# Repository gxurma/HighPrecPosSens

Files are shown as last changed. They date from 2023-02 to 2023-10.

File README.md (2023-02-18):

# HighPrecPosSens

High precision Position Sensor System using
* Hamamatsu s12443, 
* a gradient lens array,
* a paper or metal stripe / code encoder scale 
* an RP2040 or Teensy 4.1 µC board.

## s12443

Pixel size: 7 x 125 μm, 2496 pixels, small package

The S12443 is a CMOS linear image sensor with a compact yet 2496-pixel long photosensitive area (effective photosensitive area length: 17.472 mm). The pixel size is 7 x 125 μm.

* Features
* Pixel size: 7 × 125 μm
* 2496 pixels
* Effective photosensitive area length: 17.472 mm
* 3.3 V single power supply operation
* Built-in timing generator allows operation with only Start and Clock pulse inputs
* Video data rate: 10 MHz max.
* Small imput terminal capacitance: 5 pF

In my experiments I saw that 10MHz usage is leading to higher noise levels.

I recommend 5 MHz pxel clock signal, thats nicely representing the measured analog signal.

## Credits to

https://github.com/ncarandini/KiCad-RP-Pico.git

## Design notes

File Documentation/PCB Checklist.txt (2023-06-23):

Pcb und Assembly: Checkliste
============================
Martin Gyurkó <martin.gyurko@engyneer.de>
v1.0, {docdate}: valami
:toc:
:toclevels: 3
:icons: font
:doctype: article
:chapter-label:
:table-stripes: odd

* [ ] Kontur
* [ ] Bohrungen
* [ ] Copyright 
* [ ] Author Name
* [ ] Device Name
* [ ] Versionsnummer
* [ ] JlcPcb String
* [ ] Mounting attribute at relevant parts, Do not populate (DNP) if not needed
* [ ] Net names on relevant and all power nets
* [ ] Set net classes to power and signal
* [ ] Logo!
* [ ] Testpunkte!
* [ ] Via bohrdurchmesser checken und alle einheitlich anpassen
* [ ] Stecker Footprints checken - Male / Female
* [ ] Layer Stackup Beschreibung einfügen (Lagendicken, material etc.)
* [ ] DRC Regeln einstellen und durchführen

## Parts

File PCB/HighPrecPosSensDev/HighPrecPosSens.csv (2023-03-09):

Comment | Designator | Footprint | LCSC Part # | Mounting
100n Unpolarized capacitor | C1,C3,C9,C10,C13,C14,C16,C21 | C_0603_1608Metric | C14663
10u Unpolarized capacitor | C2 | C_0805_2012Metric_Pad1.18x1.45mm_HandSolder | C440198
100u Unpolarized capacitor | C4 | C_1206_3216Metric_Pad1.33x1.80mm_HandSolder | C15008
150p Unpolarized capacitor | C5 | C_0603_1608Metric | C1594
22u Unpolarized capacitor | C6,C7,C11,C12,C15 | C_0603_1608Metric | C59461
1u Unpolarized capacitor | C8,C17,C18,C19,C20 | C_0603_1608Metric | C15849
LED Light emitting diode | D1,D2,D3,D4,D5,D6,D7,D9,D10,D11,D12,D13,D14,D15 | LED_0603_1608Metric_Pad1.05x0.95mm_HandSolder | C72041
SS36 Schottky diode, filled shape | D8 | D_SMC_Handsoldering | C35722
Fiducial Fiducial Marker | FID1,FID2,FID3,FID4 | Fiducial_1mm_Mask2mm |  | DNP
LOGO | G1 | enGyneer-Logo |  | DNP
MountingHole_Pad Mounting Hole with connection | H1,H2,H3,H4 | MountingHole_3.2mm_M3_Pad |  | DNP
Conn_01x02_Male Generic connector, single row, 01x02, script generated (kicad-library-utils/schlib/autogen/connector/) | J1,J2,J3,J4,J6,J7,J8 | PinHeader_1x02_P2.54mm_Vertical |  | DNP
Conn_01x06_Male Generic connector, single row, 01x06, script generated (kicad-library-utils/schlib/autogen/connector/) | J5 | JST_XH_B6B-XH-A_1x06_P2.50mm_Vertical | C144397 | DNP
10u Inductor | L1 | L_Taiyo-Yuden_NR-50xx_HandSoldering | C222896
82 Resistor | R1,R5,R6,R7,R8,R15,R16,R17,R18,R19,R20,R25,R26,R27,R28,R29 | R_0603_1608Metric | C23255
47k Resistor | R2 | R_0603_1608Metric | C25819
4.7k Resistor | R3 | R_0603_1608Metric | C23162
2.7k Resistor | R4 | R_0603_1608Metric | C13167
100 Resistor | R9 | R_0603_1608Metric | C22775
3.6k Resistor | R10 | R_0603_1608Metric | C22980
1k Resistor | R11,R12,R13,R21,R22,R23,R24 | R_0603_1608Metric | C21190
4.3k Resistor | R14 | R_0603_1608Metric | C23159
TestPoint test point | TP1,TP2,TP3,TP4 | TestPoint_THTPad_D1.5mm_Drill0.7mm |  | DNP
ST1S14PHR 3A step-down switching regulator, Adjustable Output Voltage, 5.5-48V Input Voltage, 850kHz, PowerSO-8 | U1 | TI_SO-PowerPAD-8 | C84130
S12443 Hamamatsu Linear CMOS Sensor 7 x 125µm, 2496 pixels | U2 | s12443 |  | DNP
LM393DR2G Low-Power, Low-Offset Voltage, Dual Comparators, DIP-8/SOIC-8/TO-99-8 | U3,U4 | SOIC-8_3.9x4.9mm_P1.27mm | C7955
74LVC541A 8-bit Buffer/Line Driver 3-state outputs | U5 | TSSOP-20_4.4x6.5mm_P0.65mm | C6093
Pico | U6 | RPi_Pico_SMD_TH |  | DNP

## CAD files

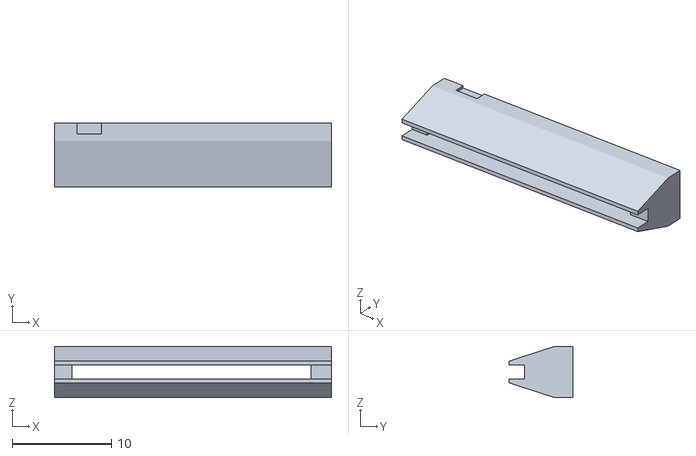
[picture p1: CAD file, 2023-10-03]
PCB/HighPrecPosSensDev/Deckel2.stl
27.9 x 6.40 x 5.19

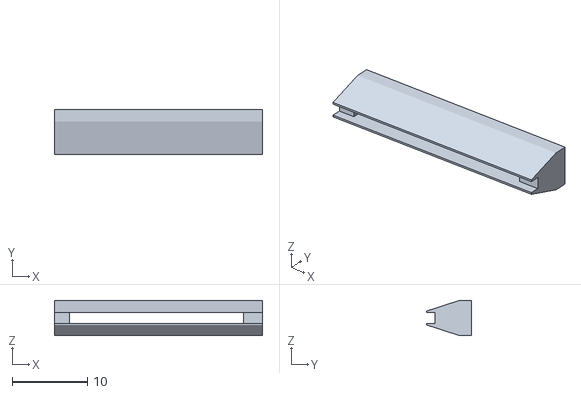
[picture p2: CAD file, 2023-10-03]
PCB/HighPrecPosSensDev/Deckel.stl
27.7 x 6.00 x 4.69

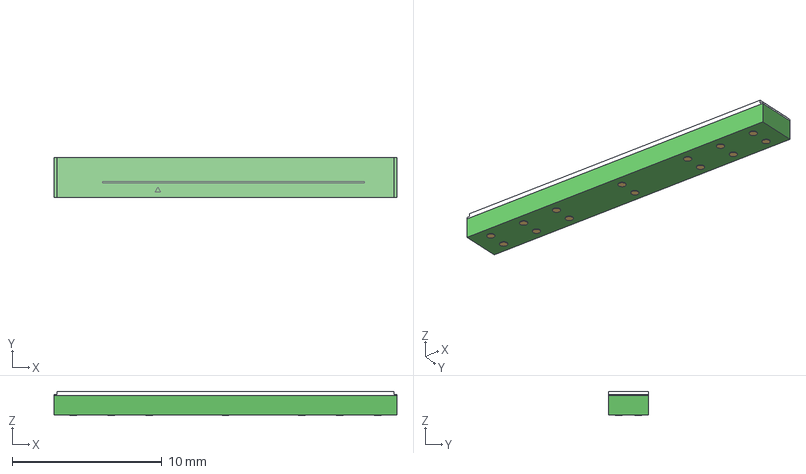
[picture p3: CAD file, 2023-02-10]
CAD/s12443.stp
22.9 x 2.70 x 1.64 mm
s12443
s12443_deckel
s12443_pads

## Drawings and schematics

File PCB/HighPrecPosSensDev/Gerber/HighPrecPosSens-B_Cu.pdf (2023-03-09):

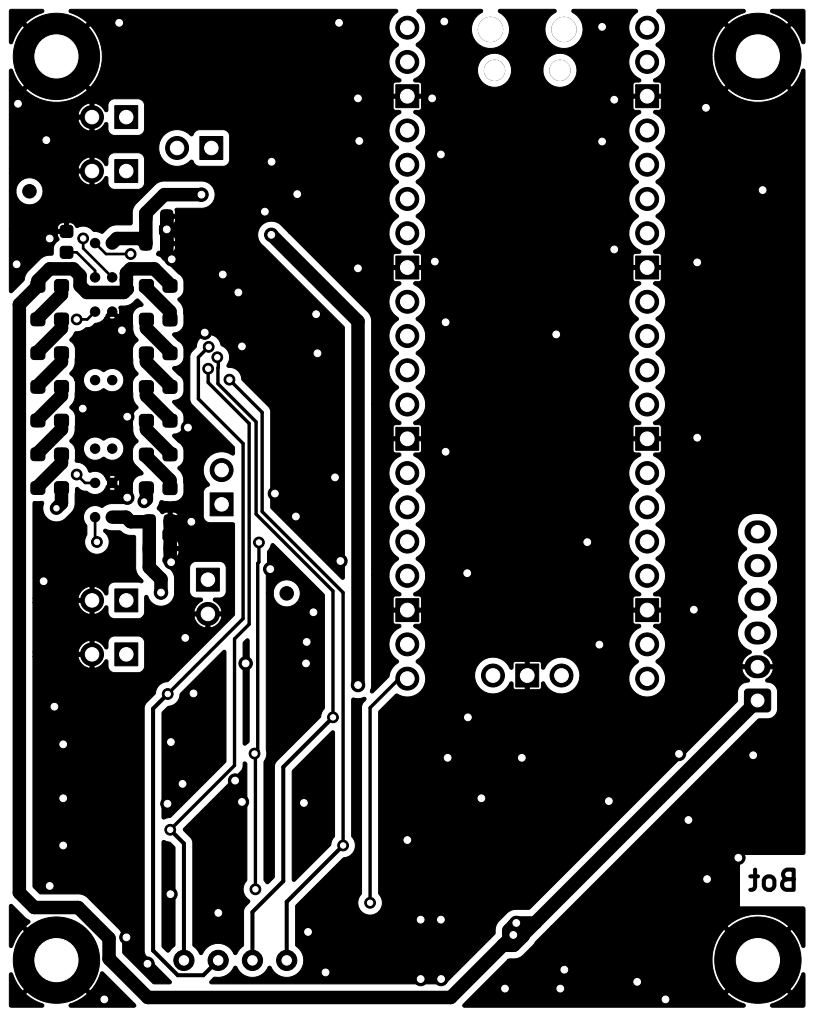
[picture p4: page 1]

www.enGyneer.de Bot

File: HighPrecPosSens.kicad_pcb Sheet: enGyneer

Id: 1/1 Title: High Precision Position Sensor

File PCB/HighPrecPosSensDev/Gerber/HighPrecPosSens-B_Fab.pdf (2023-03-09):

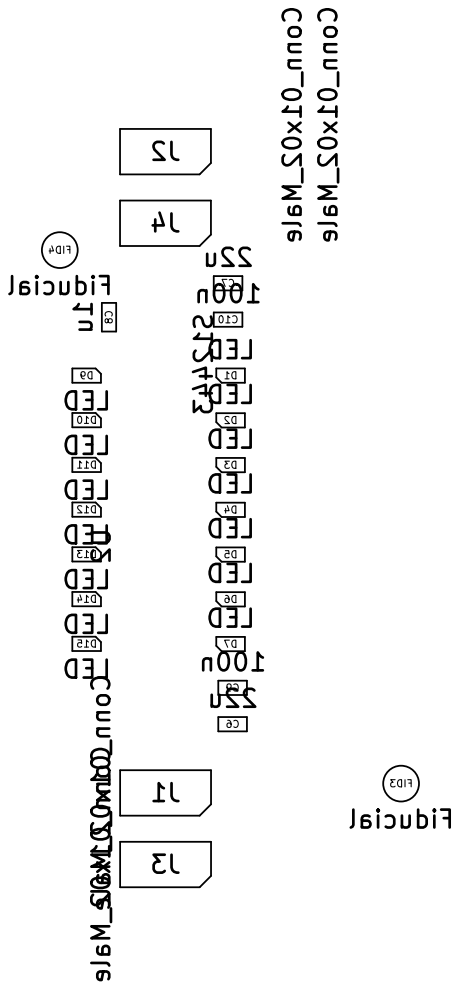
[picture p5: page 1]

File: HighPrecPosSens.kicad_pcb Sheet: enGyneer

Id: 1/1 Title: High Precision Position Sensor

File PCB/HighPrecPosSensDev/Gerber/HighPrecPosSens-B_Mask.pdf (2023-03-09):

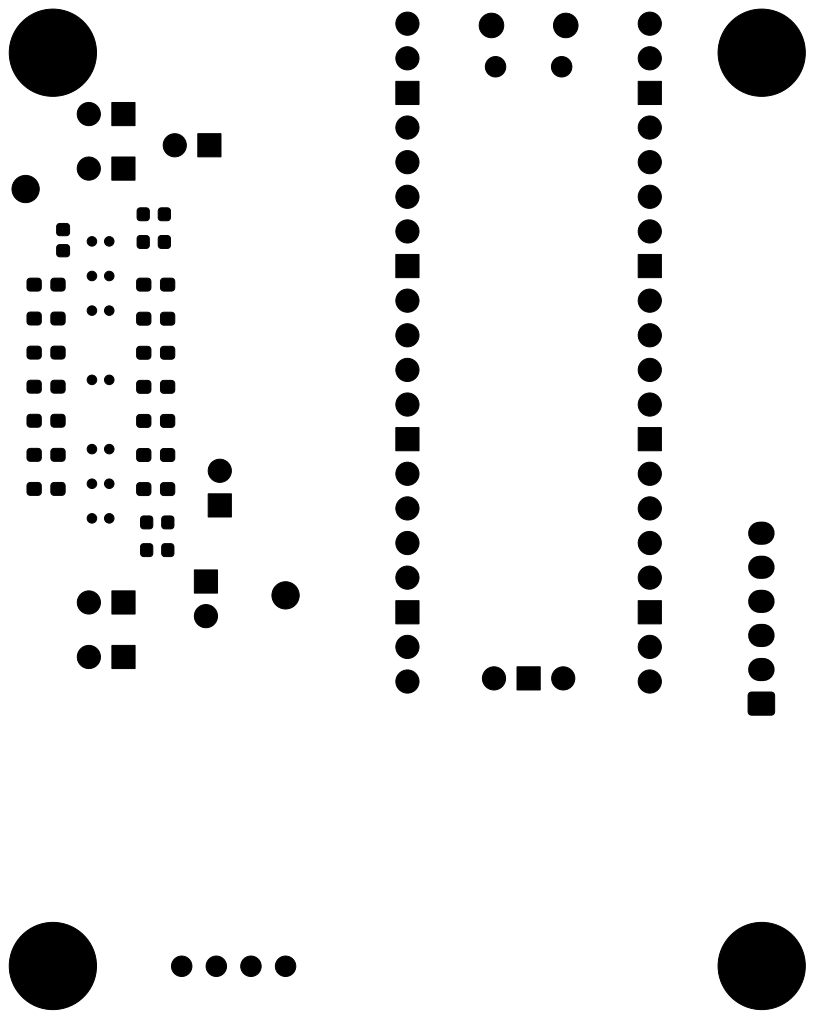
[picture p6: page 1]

File: HighPrecPosSens.kicad_pcb Sheet: enGyneer

Id: 1/1 Title: High Precision Position Sensor

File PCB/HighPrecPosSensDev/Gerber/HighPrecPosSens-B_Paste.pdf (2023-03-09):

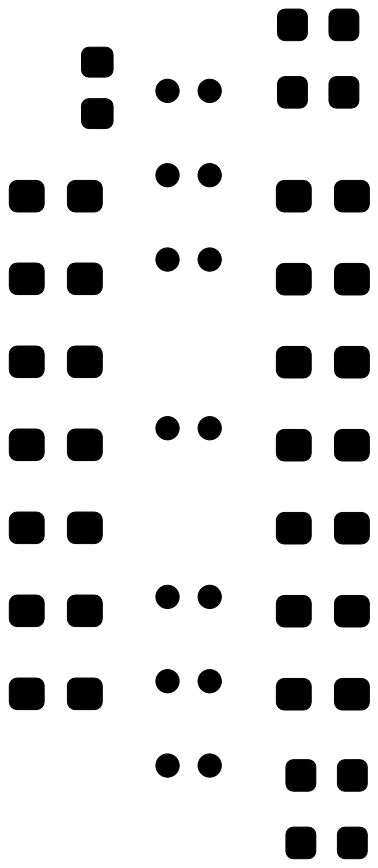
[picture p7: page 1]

File: HighPrecPosSens.kicad_pcb Sheet: enGyneer

Id: 1/1 Title: High Precision Position Sensor

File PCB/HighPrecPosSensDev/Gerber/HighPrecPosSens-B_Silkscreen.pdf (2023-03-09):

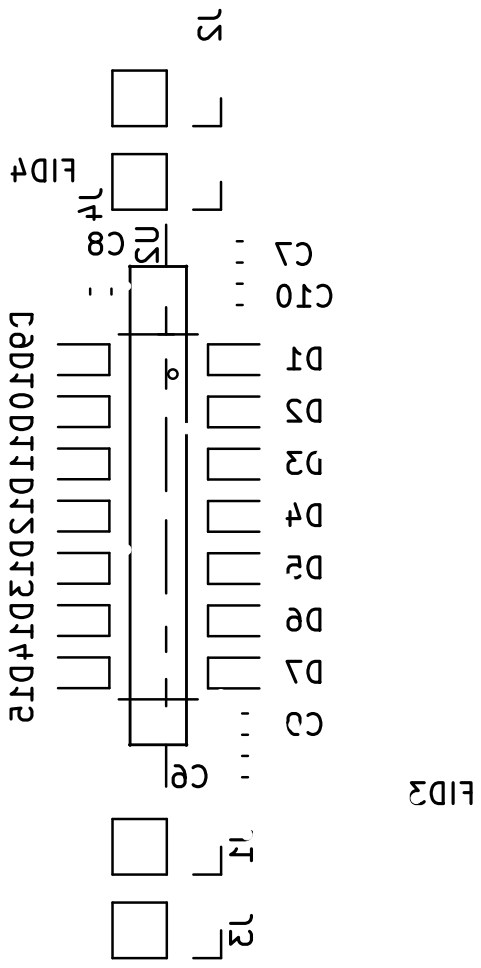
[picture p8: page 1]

File: HighPrecPosSens.kicad_pcb Sheet: enGyneer

Id: 1/1 Title: High Precision Position Sensor

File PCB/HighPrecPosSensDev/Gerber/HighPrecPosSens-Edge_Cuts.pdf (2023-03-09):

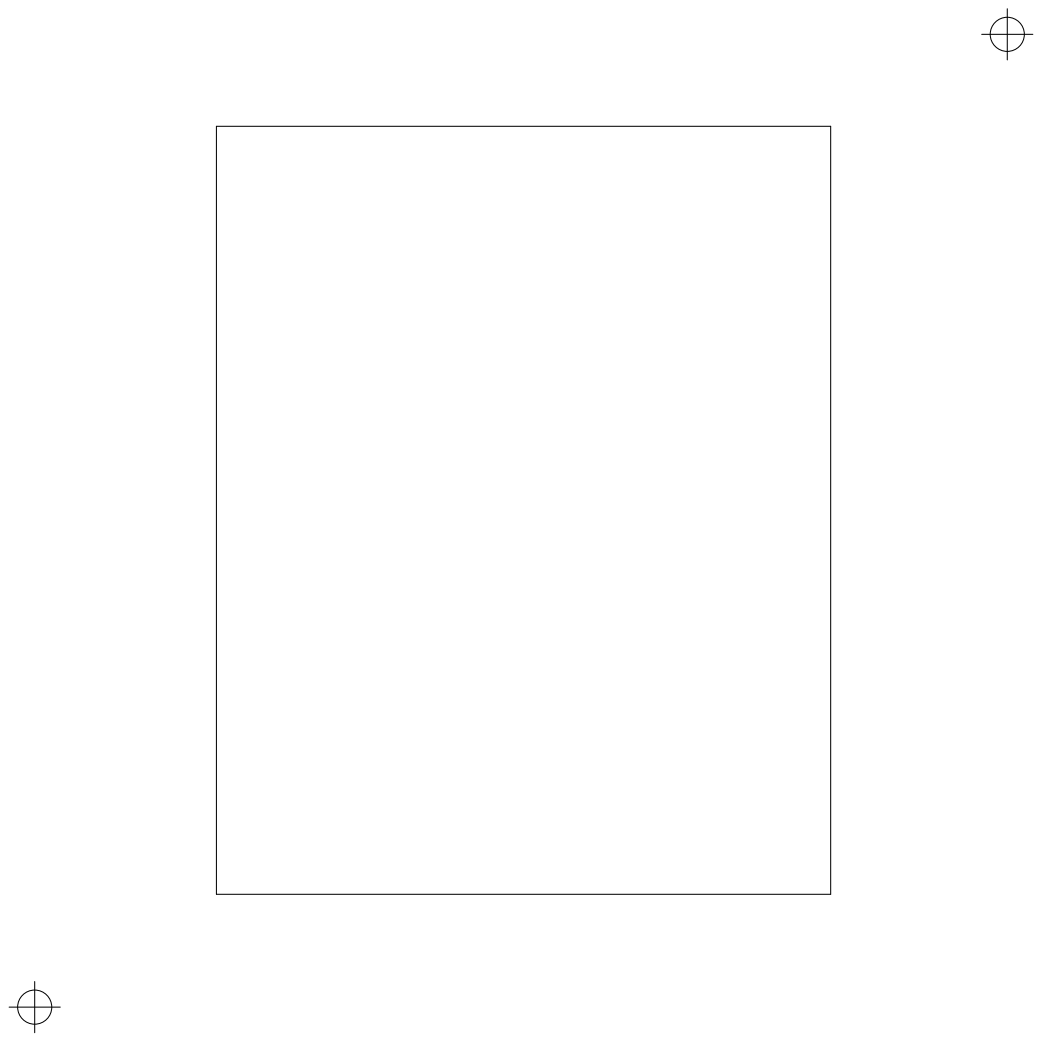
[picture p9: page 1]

File: HighPrecPosSens.kicad_pcb Sheet: enGyneer

Id: 1/1 Title: High Precision Position Sensor

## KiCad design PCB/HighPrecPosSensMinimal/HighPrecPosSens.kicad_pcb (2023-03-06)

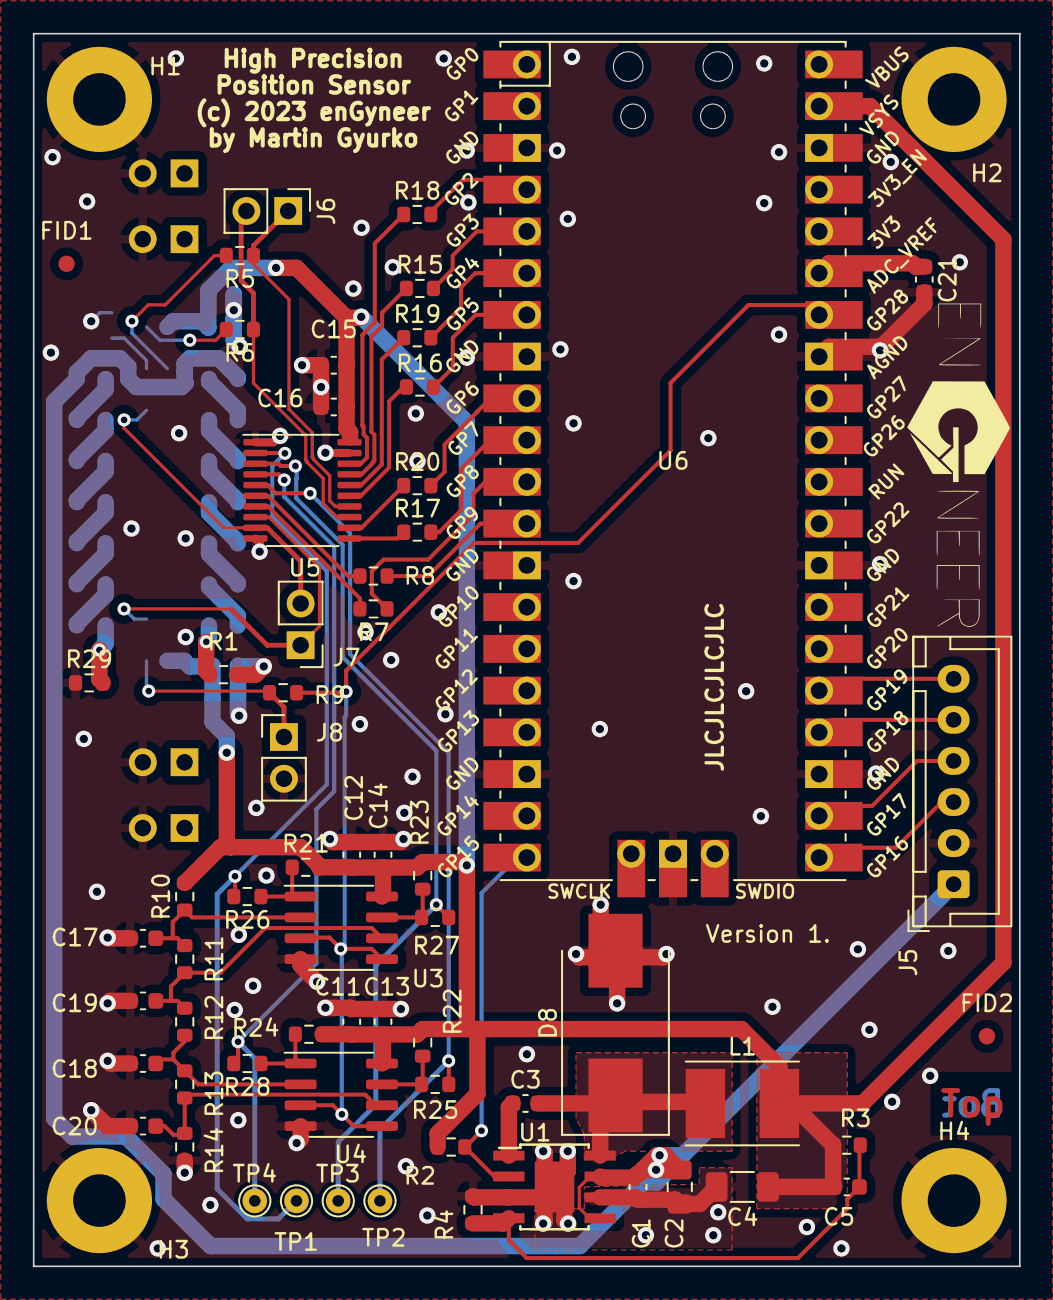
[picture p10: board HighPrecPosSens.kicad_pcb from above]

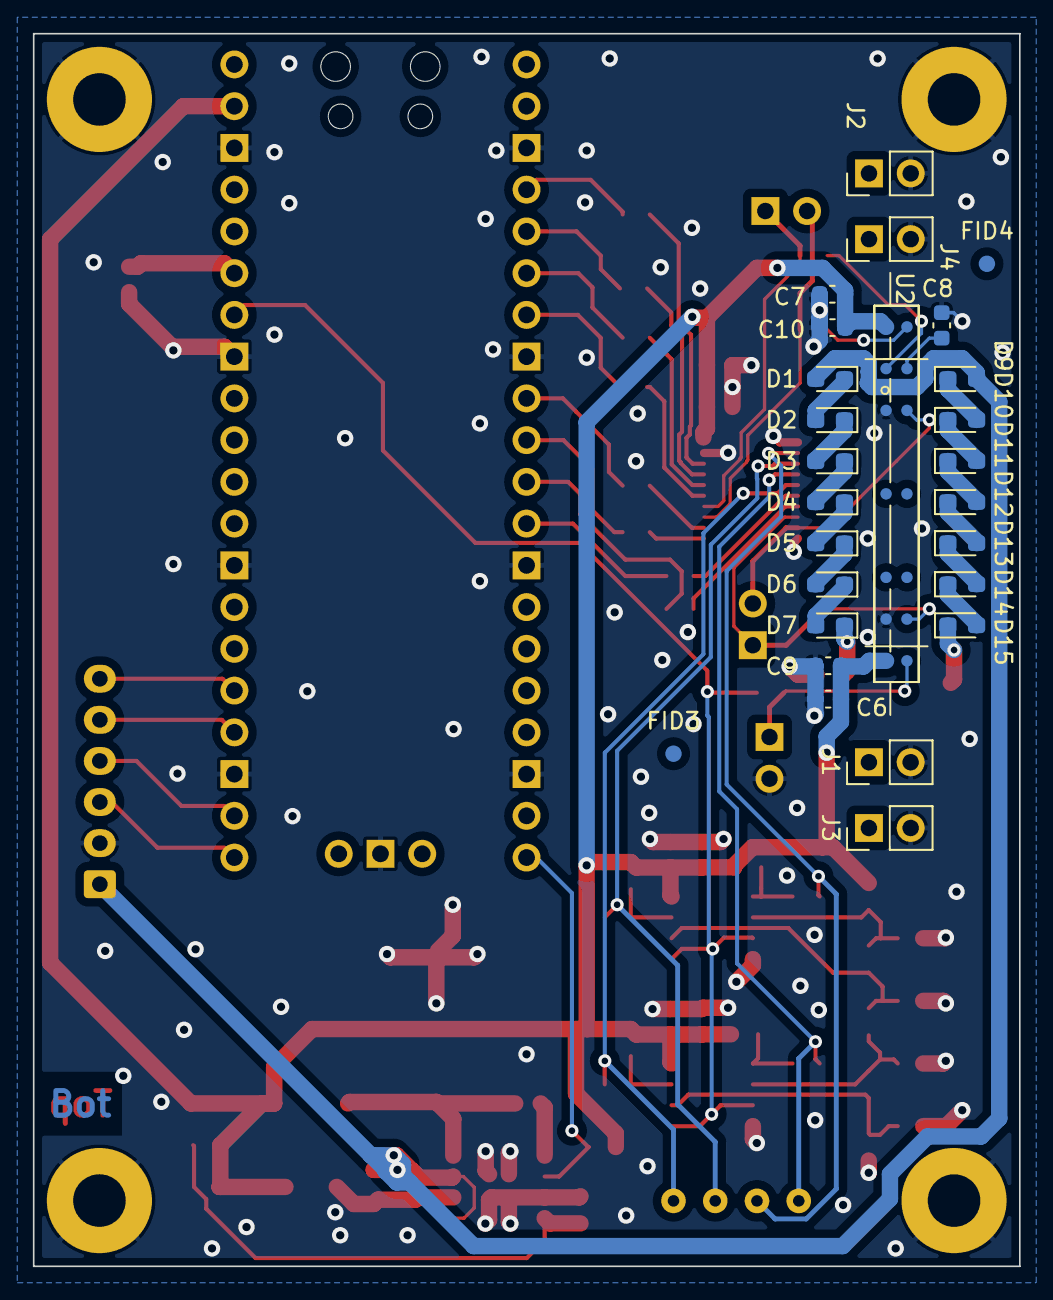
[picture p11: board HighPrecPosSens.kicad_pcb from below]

Board: 2 copper layers, 60.0 x 75.0 mm, 93 parts (26 on the bottom side), 63 nets.

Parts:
C1, C3, C9, C10, C13, C14, C16, C21: 100n; C_0603_1608Metric
C2: 10u; C_0805_2012Metric_Pad1.18x1.45mm_HandSolder
C4: 100u; C_1206_3216Metric_Pad1.33x1.80mm_HandSolder
C5: 150p; C_0603_1608Metric
C6, C7, C11, C12, C15: 22u; C_0603_1608Metric
C8, C17, C18, C19, C20: 1u; C_0603_1608Metric
D1, D2, D3, D4, D5, D6, D7, D9, D10, D11, D12, D13, D14, D15: LED; LED_0603_1608Metric_Pad1.05x0.95mm_HandSolder
D8: SS36; D_SMC_Handsoldering
FID1, FID2, FID3, FID4: Fiducial; Fiducial_1mm_Mask2mm
G1: LOGO; enGyneer-Logo
H1, H2, H3, H4: MountingHole_Pad; MountingHole_3.2mm_M3_Pad
J1, J2, J3, J4, J6, J7, J8: Conn_01x02_Male; PinHeader_1x02_P2.54mm_Vertical
J5: Conn_01x06_Male; JST_XH_B6B-XH-A_1x06_P2.50mm_Vertical
L1: 10u; L_Taiyo-Yuden_NR-50xx_HandSoldering
R1, R5, R6, R7, R8, R15, R16, R17, R18, R19, R20, R25, R26, R27, R28, R29: 82; R_0603_1608Metric
R2: 47k; R_0603_1608Metric
R3: 4.7k; R_0603_1608Metric
R4: 2.7k; R_0603_1608Metric
R9: 100; R_0603_1608Metric
R10: 3.6k; R_0603_1608Metric
R11, R12, R13, R21, R22, R23, R24: 1k; R_0603_1608Metric
R14: 4.3k; R_0603_1608Metric
TP1, TP2, TP3, TP4: TestPoint; TestPoint_THTPad_D1.5mm_Drill0.7mm
U1: ST1S14PHR; TI_SO-PowerPAD-8
U2: S12443; s12443
U3, U4: LM393DR2G; SOIC-8_3.9x4.9mm_P1.27mm
U5: 74LVC541A; TSSOP-20_4.4x6.5mm_P0.65mm
U6: Pico; RPi_Pico_SMD_TH

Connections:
+3.3V: C4.1, C5.1, C6.1, C7.1, C9.1, C10.1, C11.1, C12.1, C13.1, C14.1, C15.1, C16.1, L1.2, R2.1, R3.2, R10.2, R21.2, R22.2, R23.2, R24.2, U2.1 (Vdd), U2.7 (Vdd), U3.8 (V+), U4.8 (V+), U5.20 (VCC), U6.39 (VSYS)
+24V: C1.1, C2.1, D1.2 (A), D9.2 (A), J5.1, U1.5 (EN2), U1.7 (VIN)
/Boot: C3.1, U1.1 (BOOT)
/CLk: J6.1, R5.1, U5.14 (Y4)
/Clk_2: R5.2, U2.2 (Clk)
/D1: R25.2, TP2.1, U5.5 (A3)
/D2: R28.2, TP4.1, U5.4 (A2)
/D3: R27.2, TP3.1, U5.3 (A1)
/D4: R26.2, TP1.1, U5.2 (A0)
/EOS: J7.1, U2.9 (EOS), U5.8 (A6)
/FB: C5.2, R3.1, R4.2, U1.4 (FB)
/ST: J6.2, R6.1, U5.13 (Y5)
/ST_2: R6.2, U2.14 (ST)
/Switch: C3.2, D8.1 (K), L1.1, U1.8 (SW)
/Trig: J7.2, U2.12 (Trig), U5.9 (A7)
/V1: C20.1, R13.1, R14.2, U4.6 (-)
/V2: C18.1, R12.1, R13.2, U4.2 (-)
/V3: C19.1, R11.1, R12.2, U3.6 (-)
/V4: C17.1, R10.1, R11.2, U3.2 (-)
/Video: J8.1, R9.1, U2.8 (Video)
/Video1: R9.2, U3.3 (+), U3.5 (+), U4.3 (+), U4.5 (+), U6.34 (GPIO28_ADC2)
GND: C1.2, C2.2, C4.2, C6.2, C7.2, C8.2, C9.2, C10.2, C11.2, C12.2, C13.2, C14.2, C15.2, C16.2, C17.2, C18.2, C19.2, C20.2, C21.2, D8.2 (A), H1.1, H2.1, H3.1, H4.1, J1.2, J2.2, J3.2, J4.2, J5.2, J8.2, R1.1, R4.1, R14.1, R29.1, U1.3 (~EN1), U1.6 (GND), U1.9 (PADGND), U2.3 (Vss), U2.6 (Vss), U3.4 (V-), U4.4 (V-), U5.1 (G1), U5.10 (GND), U5.19 (G2), U6.3 (GND), U6.8 (GND), U6.13 (GND), U6.18 (GND), U6.23 (GND), U6.28 (GND), U6.33 (AGND), U6.38 (GND), U6.42 (GND)
Miso: J5.3, U6.21 (GPIO16)
Mosi: J5.6, U6.25 (GPIO19)
unnamed: C8.1, U2.13 (Vcp)
unnamed: C21.1, U6.35 (ADC_VREF)
unnamed: D1.1 (K), D2.2 (A)
unnamed: D2.1 (K), D3.2 (A)
unnamed: D3.1 (K), D4.2 (A)
unnamed: D4.1 (K), D5.2 (A)
unnamed: D5.1 (K), D6.2 (A)
unnamed: D6.1 (K), D7.2 (A)
unnamed: D7.1 (K), R1.2
unnamed: D10.1 (K), D11.2 (A)
unnamed: D9.1 (K), D10.2 (A)
unnamed: D11.1 (K), D12.2 (A)
unnamed: D12.1 (K), D13.2 (A)
unnamed: D13.1 (K), D14.2 (A)
unnamed: D14.1 (K), D15.2 (A)
unnamed: D15.1 (K), R29.2
unnamed: R7.1, U6.11 (GPIO8)
unnamed: R7.2, U5.7 (A5)
unnamed: R8.1, U6.12 (GPIO9)
unnamed: R8.2, U5.6 (A4)
unnamed: R15.1, U5.17 (Y1)
unnamed: R15.2, U6.5 (GPIO3)
unnamed: R16.1, U5.15 (Y3)
unnamed: R16.2, U6.7 (GPIO5)
unnamed: R17.1, U5.11 (Y7)
unnamed: R17.2, U6.10 (GPIO7)
unnamed: R18.1, U5.18 (Y0)
unnamed: R18.2, U6.4 (GPIO2)
unnamed: R19.1, U5.16 (Y2)
unnamed: R19.2, U6.6 (GPIO4)
unnamed: R20.1, U5.12 (Y6)
unnamed: R20.2, U6.9 (GPIO6)
unnamed: R21.1, R26.1, U3.1
unnamed: R22.1, R25.1, U4.7
unnamed: R23.1, R27.1, U3.7
unnamed: R24.1, R28.1, U4.1
PGood: R2.2, U1.2 (PG), U6.20 (GPIO15)
SCS: J5.4, U6.22 (GPIO17)
SCkl: J5.5, U6.24 (GPIO18)

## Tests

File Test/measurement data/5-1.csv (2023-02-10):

Time | x
s | logic
-0.0004999992 | 53.
-0.0004998392 | 53.
-0.0004996792 | 53.
-0.0004995192 | 53.
-0.0004993592 | 53.
-0.0004991992 | 53.
-0.0004990392 | 53.
-0.0004988792 | 53.
-0.0004987192 | 53.
-0.0004985592 | 53.
-0.0004983992 | 158.
-0.0004982392 | 158.
-0.0004980792 | 159.
-0.0004979192 | 159.
-0.0004977592 | 158.
-0.0004975992 | 158.
-0.0004974392 | 158.
-0.0004972792 | 158.
-0.0004971192 | 158.
-0.0004969592 | 158.
-0.0004967992 | 158.
-0.0004966392 | 158.
-0.0004964792 | 158.
-0.0004963192 | 158.
-0.0004961592 | 159.
-0.0004959992 | 158.
-0.0004958392 | 158.
-0.0004956792 | 158.
-0.0004955192 | 158.
-0.0004953592 | 158.
-0.0004951992 | 158.
-0.0004950392 | 158.
-0.0004948792 | 158.
-0.0004947192 | 158.
-0.0004945592 | 159.
-0.0004943992 | 159.
-0.0004942392 | 158.
-0.0004940792 | 159.
-0.0004939192 | 159.
-0.0004937592 | 158.
-0.0004935992 | 158.
-0.0004934392 | 158.
-0.0004932792 | 158.
-0.0004931192 | 158.
-0.0004929592 | 159.
-0.0004927992 | 158.
-0.0004926392 | 159.
-0.0004924792 | 158.
-0.0004923192 | 158.
-0.0004921592 | 157.
-0.0004919992 | 158.
-0.0004918392 | 158.
-0.0004916792 | 157.
-0.0004915192 | 157.
-0.0004913592 | 159.
-0.0004911992 | 157.
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

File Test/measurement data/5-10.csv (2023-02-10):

Time | x
s | logic
-0.0004999992 | 53.
-0.0004998392 | 53.
-0.0004996792 | 53.
-0.0004995192 | 53.
-0.0004993592 | 53.
-0.0004991992 | 53.
-0.0004990392 | 53.
-0.0004988792 | 53.
-0.0004987192 | 53.
-0.0004985592 | 53.
-0.0004983992 | 75.
-0.0004982392 | 75.
-0.0004980792 | 75.
-0.0004979192 | 75.
-0.0004977592 | 76.
-0.0004975992 | 76.
-0.0004974392 | 76.
-0.0004972792 | 76.
-0.0004971192 | 76.
-0.0004969592 | 76.
-0.0004967992 | 77.
-0.0004966392 | 78.
-0.0004964792 | 78.
-0.0004963192 | 78.
-0.0004961592 | 79.
-0.0004959992 | 80.
-0.0004958392 | 80.
-0.0004956792 | 82.
-0.0004955192 | 82.
-0.0004953592 | 83.
-0.0004951992 | 84.
-0.0004950392 | 85.
-0.0004948792 | 87.
-0.0004947192 | 87.
-0.0004945592 | 90.
-0.0004943992 | 92.
-0.0004942392 | 96.
-0.0004940792 | 100.
-0.0004939192 | 100.
-0.0004937592 | 105.
-0.0004935992 | 111.
-0.0004934392 | 117.
-0.0004932792 | 122.
-0.0004931192 | 122.
-0.0004929592 | 129.
-0.0004927992 | 135.
-0.0004926392 | 141.
-0.0004924792 | 146.
-0.0004923192 | 146.
-0.0004921592 | 149.
-0.0004919992 | 152.
-0.0004918392 | 154.
-0.0004916792 | 154.
-0.0004915192 | 154.
-0.0004913592 | 156.
-0.0004911992 | 155.
-0.0004910392 | 156.
-0.0004908792 | 157.
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

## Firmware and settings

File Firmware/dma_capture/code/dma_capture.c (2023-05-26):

/**
 * Copyright (c) 2021 Raspberry Pi (Trading) Ltd.
 *
 * SPDX-License-Identifier: BSD-3-Clause
 */

#include <stdio.h>
#include "pico/stdlib.h"
// For ADC input:
#include "hardware/adc.h"
#include "hardware/dma.h"
// For resistor DAC output:
#include "pico/multicore.h"
#include "hardware/pio.h"
#include "resistor_dac.pio.h"

// This example uses the DMA to capture many samples from the ADC.
//
// - We are putting the ADC in free-running capture mode at 0.5 Msps
//
// - A DMA channel will be attached to the ADC sample FIFO
//
// - Configure the ADC to right-shift samples to 8 bits of significance, so we
//   can DMA into a byte buffer
//
// This could be extended to use the ADC's round robin feature to sample two
// channels concurrently at 0.25 Msps each.
//
// It would be nice to have some analog samples to measure! This example also
// drives waves out through a 5-bit resistor DAC, as found on the reference
// VGA board. If you have that board, you can take an M-F jumper wire from
// GPIO 26 to the Green pin on the VGA connector (top row, next-but-rightmost
// hole). Or you can ignore that part of the code and connect your own signal
// to the ADC input.

// Channel 0 is GPIO26
#define CAPTURE_CHANNEL 2
int CAPTURE_DEPTH = 3000;

uint8_t capture_buf[6000];

bool Capturing = false;

void core1_main();

int main() {
    char tmp;
    stdio_init_all();

    // Send core 1 off to start driving the "DAC" whilst we configure the ADC.
    multicore_launch_core1(core1_main);

    // Init GPIO for analogue use: hi-Z, no pulls, disable digital input buffer.
    adc_gpio_init(26 + CAPTURE_CHANNEL);

    adc_init();
    adc_select_input(CAPTURE_CHANNEL);
    adc_fifo_setup(
        true,    // Write each completed conversion to the sample FIFO
        true,    // Enable DMA data request (DREQ)
        1,       // DREQ (and IRQ) asserted when at least 1 sample present
        false,   // We won't see the ERR bit because of 8 bit reads; disable.
        true     // Shift each sample to 8 bits when pushing to FIFO
    );

    // Divisor of 0 -> full speed. Free-running capture with the divider is
    // equivalent to pressing the ADC_CS_START_ONCE button once per `div + 1`
    // cycles (div not necessarily an integer). Each conversion takes 96
    // cycles, so in general you want a divider of 0 (hold down the button
    // continuously) or > 95 (take samples less frequently than 96 cycle
    // intervals). This is all timed by the 48 MHz ADC clock.
    adc_set_clkdiv(0);

    printf("Arming DMA\n");
    sleep_ms(1000);
    // Set up the DMA to start transferring data as soon as it appears in FIFO
    uint dma_chan = dma_claim_unused_channel(true);
    dma_channel_config cfg = dma_channel_get_default_config(dma_chan);

    // Reading from constant address, writing to incrementing byte addresses
    channel_config_set_transfer_data_size(&cfg, DMA_SIZE_8);
    channel_config_set_read_increment(&cfg, false);
    channel_config_set_write_increment(&cfg, true);

    // Pace transfers based on availability of ADC samples
    channel_config_set_dreq(&cfg, DREQ_ADC);
    adc_run(true);
while(true)
{
    int i;
    // printf("Starting capture\n");
    dma_channel_configure(dma_chan, &cfg,
        capture_buf,    // dst
        &adc_hw->fifo,  // src
        CAPTURE_DEPTH,  // transfer count
        true            // start immediately
    );

    Capturing = true;

    // Once DMA finishes, stop any new conversions from starting, and clean up
    // the FIFO in case the ADC was still mid-conversion.
    dma_channel_wait_for_finish_blocking(dma_chan);
    // adc_run(false);
    // adc_fifo_drain();
    // // printf("Capture finished\n");

    bool once = true;
    int startpos = 0;

    // Print samples to stdout so you can display them in pyplot, excel, matlab
    /*for (int i = 0; i < CAPTURE_DEPTH; ++i) {
        tmp = capture_buf[i];
        if ((tmp >= 55)&& once) //synchronisation not perfect, need to find first sample
        {  */
            printf("\n Startpos: %d \n DataStart:", i);/*
            once = false;
            startpos = i;
        }

        if (!once ) //&& i< (startpos + 2497))
        {    //printf("%02X;", tmp);*/
            fwrite(capture_buf,1,CAPTURE_DEPTH, stdout); //debug to usb
            fflush(stdout);
      /*      break;
        }
*/
        
        // if (i % 60 == 59)
            // printf("\n");
 //   }
    printf(":DataEnd\n");

char dummy[12];
scanf("%d",&CAPTURE_DEPTH);

}
}

// ----------------------------------------------------------------------------
// Code for driving the "DAC" output for us to measure

// Core 1 is just going to sit and drive samples out continously. PIO provides
// consistent sample frequency.

#define OUTPUT_FREQ_HZ 1000000
#define OUT_SAMPLES 2591
#define STLength 100

// This is the green channel on the VGA board
#define OUTPUT_PIN_BASE 8

#define ONPHASE 6


void core1_main() {
    PIO pio = pio0;
    uint sm = pio_claim_unused_sm(pio0, true);
    uint offset = pio_add_program(pio0, &resistor_dac_2bit_program);
    resistor_dac_2bit_program_init(pio0, sm, offset, OUTPUT_FREQ_HZ, OUTPUT_PIN_BASE);
    // int counter = 0;


    while (true) {
        if (Capturing)
        {
            // outputting signal
            pio_sm_put_blocking(pio, sm, (STLength << 16) + OUT_SAMPLES );  //Start Pio SM to output one read cycle
            Capturing = false; // only capture once
        }
    }
}

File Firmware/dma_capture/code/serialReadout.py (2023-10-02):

import serial
import time
from matplotlib import pyplot as plt
import numpy as np
from calibrationfile import amin, amax, b

calibrating = False
# calibrating = True
aufnahme = False
# aufnahme = True
wiedergabe = False
# wiedergabe = True
doplot = False
# doplot = True

calfaktor = 369.5/52363.0
# calfaktor=0.007

deltamin = 3000
deltamax = 0
cutoffstart = 67
cutoff = cutoffstart - 1
cutoffend = cutoffstart
print(cutoff)
position = 0
aold = []
k=0.995
c = []
cavg = []
cold = []
e = []
counter = 0
maxindexold1 = 1024 
maxindexold2 = 1024
maxindex1 = 1024
maxindex2 = 1024

if not wiedergabe:
    s = serial.Serial('COM6')  #adjust port to your needs

if doplot : plt.ion()
message = "2700\n"
first = True

while (cutoff < cutoffend):
    print()
    cutoff = cutoff + 1

    if aufnahme: 
        flog = open("Aufnahme23.txt","bw")
    if wiedergabe:
        flog = open("Aufnahme23.txt","br")

    position = 0
    delta = 0
    
    while(True) :
        
        
        # if (counter > 1353) and (counter < 1361): doplot = True
        # if (position > 12500) and (position < 14000): doplot = True
        # else : doplot = False 

        if not wiedergabe:
            s.write(message.encode())

            res = s.readline()

            # print(res)

            res = s.readline()

            # print(res)

            res = s.readline()

            # print(res)

        else : # if wiedergabe:
            res = flog.readline()
            if len(res) == 0 :  break

        if aufnahme :
            flog.write(res)
            flog.flush()
        
        counter = counter +1
        
        if counter < 10 : 
            continue

        t= range(len(res))
        a= list(res)
        # t = t[200:-54]
        # a= a[200:-54]
        t = t[200:2248]
        a= a[200:2248]
        # print (len(t), len(a))

        if first :
            if calibrating:
                amax = a.copy()
                amin = a.copy()
            aold = a.copy()
            c = a.copy()
            cold = a.copy()
            cavg = a.copy()
            e = a.copy()
            e[-1]=0
            first = False
            print(first)

        # print(a)
        if not aufnahme:
            if doplot : plt.figure(1)
            if doplot : plt.cla()
        # fig, (ax1,ax2) = if doplot : plt.subplots(2)
            if doplot : plt.plot(t,a)
        # xmin,xmax,ymin,ymax = if doplot : plt.axis()
        # print(len(a) )
        # print(xmin,xmax,ymin,ymax)
        # print(a[174:-53])
        # b = np.convolve(a,aold)
        # if doplot : plt.plot(b/100000)
        # time.sleep(0.5)

        # print(a[0:40])
        # print(amin[0:40])
        if (calibrating) :
            for i in range(len(a)):
                if (a[i] < amin[i]) :
                    amin[i] = a[i]
                if (a[i] > amax[i]) :
                    amax[i] = a[i]
        if not aufnahme:
            if doplot : plt.plot(t, amin)
            if doplot : plt.plot(t, amax)

        # print(amin[0:40])

        # Aufbereitung
        for j in range(len(a)):
            cold[j] = c[j]
            try:
                c[j] = (a[j] - amin[j])/(amax[j]-amin[j])*100 - 50
            except:
                None
            # cavg[j] = k*cavg[j]+(1-k)*c[j]
            #print(c[j], a[j],amin[j], end=" : ")   
        # print( c[0:40])
        # print(amin[0:40])

        if not aufnahme:

            if doplot : plt.plot(t, c)
            if doplot : plt.plot(t, cold)

        # for j in range(len(a)-1):
        #     e[j] = c[j]-c[j+1]
        # if doplot : plt.plot(t, e)
        # if doplot : plt.plot(t, cold)
        # if doplot : plt.plot(t, cavg)

        # f = np.fft.fft(c)
        # print(np.abs(f)[1:20])
        
        # if doplot : plt.plot(t, np.abs(f))
        # if doplot : plt.plot(t, g)
        # d = np.correlate(c,cold,mode="full")
        
        # c = c*np.bartlett(len(c))
        G_a = np.fft.fft(c)
        G_a[cutoff:-cutoff] = 0
        G_a[0] = 0  # keine DC Komponenten

        
        G_b = np.fft.fft(cold)
        # G_b = np.fft.fft(b)
        G_b[cutoff:-cutoff] = 0
        G_b[0] = 0 # keine DC komponenten
        # if doplot : plt.plot(G_b[1:200])

        # e = (np.fft.ifft(G_a) > 0)*50
        if not aufnahme:

            if doplot : plt.plot(t,np.fft.ifft(G_a))
            if doplot : plt.plot(t,np.fft.ifft(G_b))


        G_b_conj= np.conjugate(G_b)
        r = G_a*G_b_conj
        d = np.fft.ifft(r)
        # if doplot : plt.plot(r[1:100])



        if not aufnahme:
            if doplot : plt.figure(2)
            if doplot : plt.cla()

        h = list(d[int(len(d)/2):])
        # print(len(h))
        # if doplot : plt.plot(h)

        j = list(d[:int(len(d)/2)])
        # print(len(j))
        k = h+j
        # h = d[int(len(d)/2):] + d[:int(len(d)/2)]

        # if doplot : plt.plot(j)
        # if doplot : plt.plot(range(deltamin,deltamax),k[deltamin:deltamax])
        if doplot : plt.plot(k)


        # maxindexold1 = maxindex1
        # maxindexold2 = maxindex2

        # maxindex1 = (int) (np.argmax(k[:1024]))
        # maxindex2 = (int) (np.argmax(k[1024:])) + 1024

        maxindex = (int) (np.argmax(k))


        # if delta > len(d)/2 :
        #     delta = delta -len(d)
        
        # if maxindex < deltamin : deltamin = maxindex
        # if maxindex > deltamax : deltamax = maxindex

        # feininterpolation
#        polynoma = np.abs(k[maxindex-2:maxindex+3])
# #      polynomt = list(range(maxindex-2,maxindex+3))
#        p = np.polyfit(polynomt,polynoma,2)
#        x = -p[1]/p[0]/2
        # # print(polynoma, polynomt, p, x, maxindex)

#        delta = len(d)/2 - x

        # delta1 = len(d)/2 - maxindex1
        # delta2 = maxindex2 - len(d)/2

        delta = len(d)/2 - maxindex

        position = position + delta
        print("%03d %08d %8d %8d %8.5f %8.5f %8.5f"%(cutoff, counter, maxindex1, maxindex2, delta, position, position*calfaktor),end="\r")

        # aold = a

        # if doplot : plt.figure(3)
        # if doplot : plt.cla()
        # if doplot : plt.plot(abs(G_a[0:cutoff]))

        if not aufnahme:
            if doplot : plt.show()
            if doplot : plt.pause(0.005)
            

        if calibrating :
            if (counter > 550):
                break
        # time.sleep(0.005)
        #  print()
    if aufnahme or wiedergabe :
        flog.close()

if not wiedergabe :
    s.close()

if calibrating :

    calibf = open("calibrationfile.py","w")
    print("amin = ", amin, file=calibf)
    print("amax = ", amax, file=calibf)
    print("b = ",    b,    file=calibf)
    calibf.flush()
    calibf.close()
print()

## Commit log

2022-11-13 first measurement data for analysis and optimization
    [5-1.csv, 5-10.csv, 5-11.csv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]
2022-11-13 renamed test to Test and added csv usage to gitignore
    [5-1.csv, 5-10.csv, 5-11.csv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]
2022-11-14 added flowcsv project
2022-11-27 added pdf of sensor
2023-02-10 Added Hamamatsu Sensor SE CAD files
    [s12443.cfg]
2023-02-10 First commit of kicad design
    [HighPrecPosSens.kicad_pcb, HighPrecPosSens.kicad_sch]
2023-02-10 moved CAD data to CAD
    [s12443.cfg]
2023-02-10 Valami leiras
    [HighPrecPosSens.kicad_sch]
2023-02-10 Finished 3d model of sensor
    [s12443.cfg, s12443.stp]
2023-02-13 added some parts to it
    [HighPrecPosSens.kicad_sch]
2023-02-14 Added 2 bit ADC
    [HighPrecPosSens.kicad_sch]
2023-02-15 Added 2 bit ADC ladder and comparators
    [HighPrecPosSens.kicad_sch]
2023-02-15 added some wires and simulation of lt1818
    [HighPrecPosSens.kicad_sch]
2023-02-17 added pico to schematic
    [HighPrecPosSens.kicad_sch]
2023-02-18 added credit to https://github.com/ncarandini/KiCad-RP-Pico.git
2023-02-23 added some power supply
    [HighPrecPosSens.kicad_pcb, HighPrecPosSens.kicad_sch]
2023-02-24 added some pullups and positioned power supply better
    [HighPrecPosSens.kicad_sch]
2023-02-25 First netlist transfer
    [HighPrecPosSens.kicad_pcb, HighPrecPosSens.kicad_sch]
2023-02-26 Some layouting
    [HighPrecPosSens.kicad_pcb, HighPrecPosSens.kicad_sch]
2023-02-27 Added some missing parts and more LEDs
    [HighPrecPosSens.kicad_pcb, HighPrecPosSens.kicad_sch]
2023-02-27 Routed layout
    [HighPrecPosSens.kicad_pcb, HighPrecPosSens.kicad_sch]
2023-02-27 some mounting holes added
    [HighPrecPosSens.kicad_pcb, HighPrecPosSens.kicad_sch]
2023-02-27 Some readibility and overlap issues fixed, added some more ground vias
    [HighPrecPosSens.kicad_pcb]
2023-02-27 Added some text
    [HighPrecPosSens.kicad_pcb]
2023-02-28 Added some mounting or not definitions
    [HighPrecPosSens.kicad_pcb, HighPrecPosSens.kicad_sch]
2023-03-03 Added some reasonable testpoints
    [HighPrecPosSens.kicad_pcb, HighPrecPosSens.kicad_sch]
2023-03-03 Added logo
    [HighPrecPosSens.kicad_pcb, HighPrecPosSens.kicad_sch]
2023-03-03 moved logo
    [HighPrecPosSens.kicad_pcb]
2023-03-03 changed vias
    [HighPrecPosSens.kicad_pcb, HighPrecPosSens.kicad_sch]
2023-03-06 Some minor changes
    [HighPrecPosSens.kicad_pcb]
2023-03-09 moved stuff
    [HighPrecPosSens-B_Cu.gbr, HighPrecPosSens-B_Fab.gbr, HighPrecPosSens-B_Mask.gbr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]
2023-03-10 some minor attribute changes
    [HighPrecPosSens.kicad_sch]
2023-03-12 added simper sensor layout
    [HighPrecPosSens.kicad_pcb, HighPrecPosSens.kicad_sch]
2023-03-19 Just breaking my head with current layout
    [Stromplanung.xlsx]
2023-04-29 PWM mag keine 2 Cores Nach der ersten Sekunde bleibt PWM stehen...
2023-05-15 compiling and working code. still massive timing ans readout issues.
    [PIOReadTest.cpp]
2023-05-15 Somewhat working condition, but data readout does not give synchronized data. Something is really wrong.
    [PIOReadTest.cpp]
2023-05-22 last ino to get something going on the arduino dev. ide
2023-07-18 added laser diode pdf
2023-10-01 for better scales we use de bruijn
2023-10-03 Added 3d models
    [Deckel.stl, Deckel2.stl, HighPrecPosSens.cfg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]

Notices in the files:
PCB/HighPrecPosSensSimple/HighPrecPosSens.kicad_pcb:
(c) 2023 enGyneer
